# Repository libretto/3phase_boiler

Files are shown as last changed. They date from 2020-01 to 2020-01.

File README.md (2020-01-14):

# 3phase boiler controller project
Arduino based control unit circuit and firmware

# WARNING!!!  This code was created for my own test and study purposes and finally was implemented in DIY project for three phase 360V heater.
# DISCLAIMER! Any reproducing of the unit and usage it with high voltage devices is at your own risk!

History of project: 
I had cheap 12kW (360V) water heater in home climate system which had a problem with contactor frequently and I replaced it few times per season. 
To avoid this issue I decide include Solid State Relays with digital thermostat to heater circuit (serial connection to contactor based termostat for better safety).
This solution replaced mechanical switching with spark which destroy contactor to semiconductor switching and algorithm in thermostat reduced switches of heater to possible minimum.
I decide create my own thermostat circuit using Arduino nano as module to which i can connect LCD, Encoder, Sensors and SSR (or magnetic relay for other appliances). 

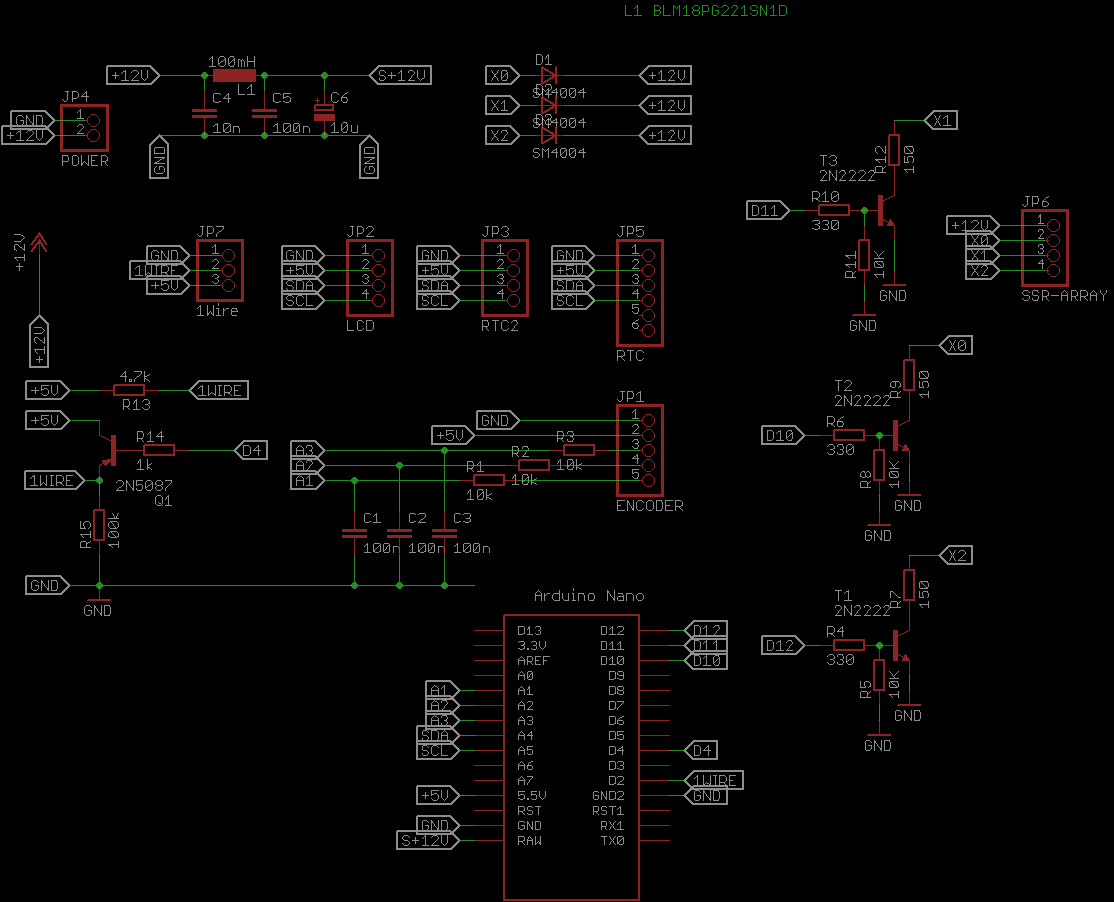
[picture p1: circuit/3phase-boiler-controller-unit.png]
Arduino based three phase control module circuit


Required units:

Arduino Nano, 
Encoder unit KY-040 (with 3 10k resistors on board), 
LCD 1602 with I2C adaptor, 
SSR Fotek SSR-40DA 3 pcs, 
DS18B20 thermal sensor with holder module 

List of all semiconductor components is included in Eagle project.

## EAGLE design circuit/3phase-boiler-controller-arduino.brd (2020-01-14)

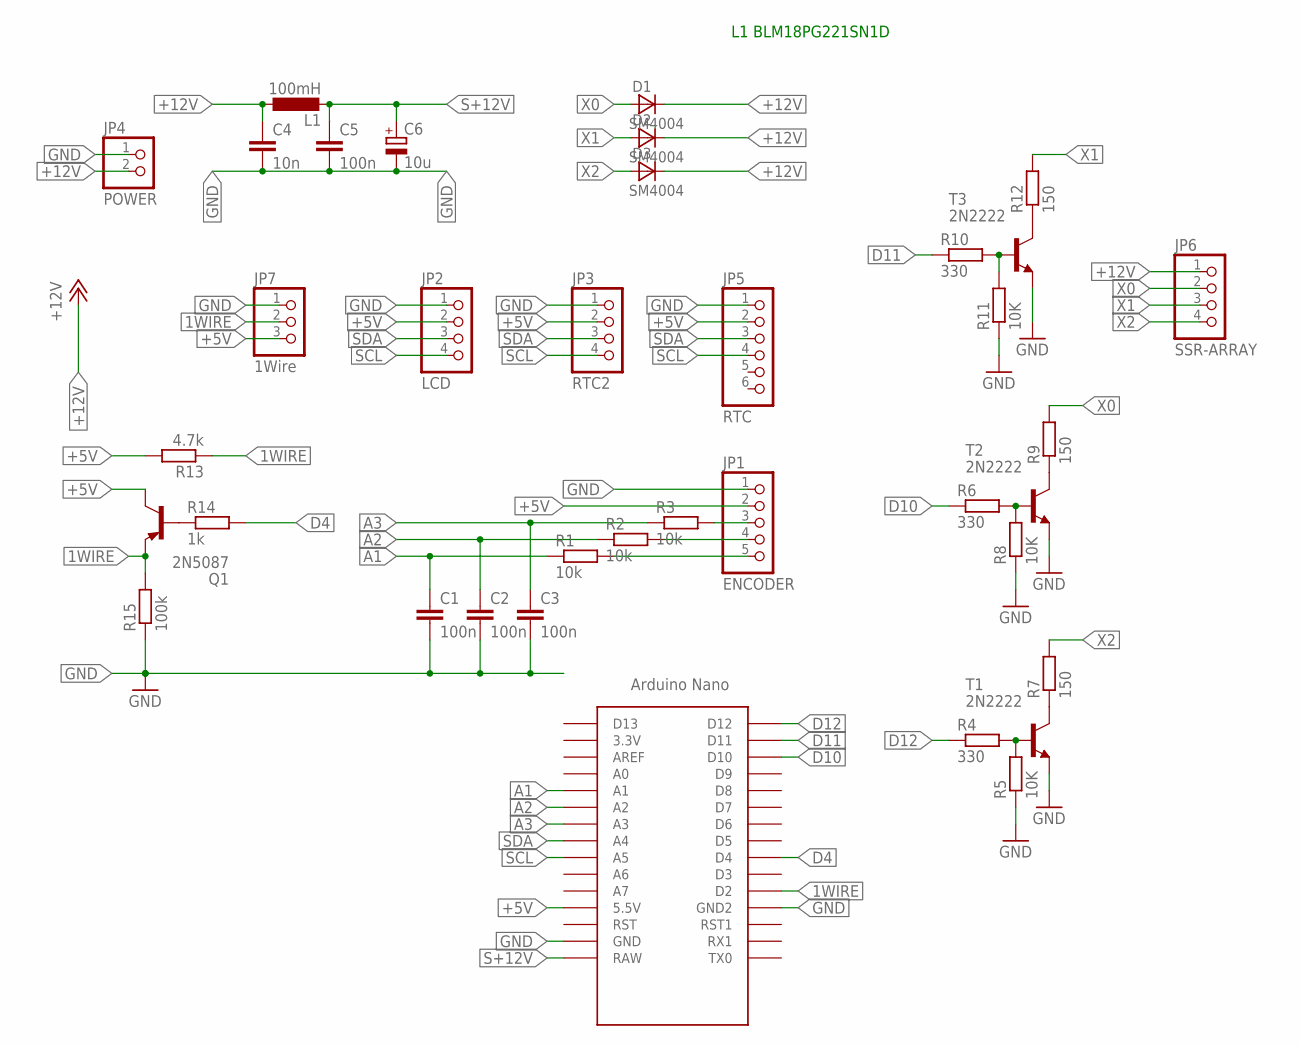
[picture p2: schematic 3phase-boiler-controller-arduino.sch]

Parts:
C1, C2, C3, C5: 100n; C0603
C4: 10n; C0603
C6: 10u; 153CLV-0807
D1, D2, D3: SM4004; MELF-MLL41
JP1: ENCODER; 1X05
JP2: LCD; 1X04
JP3: RTC2; 1X04
JP4: POWER; 1X02
JP5: RTC; 1X06/90
JP6: SSR-ARRAY; 1X04
JP7: 1Wire; 1X03
L1: 100mH; 0207/12
Q1: 2N5087; TO92
R1, R2, R3: 10k; R0805
R4, R6, R10: 330; R0805
R5, R8, R11: 10K; R0805
R7, R9, R12: 150; R0805
R13: 4.7k; R0805
R14: 1k; R0805
R15: 100k; R0805
T1, T2, T3: 2N2222; TO92-EBC-OVAL
U$1: NANO

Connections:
1WIRE: JP7.2, Q1.3 (E), R13.1, R15.2, U$1.D2
+5V: JP1.2, JP2.2, JP3.2, JP5.2, JP7.3, Q1.1 (C), R13.2, U$1.5V (5.5V)
+12V: C4.1, D1.C, D2.C, D3.C, JP4.2, JP6.1, L1.1
A1: C1.1, R1.1, U$1.A1
A2: C2.1, R2.1, U$1.A2
A3: C3.1, R3.1, U$1.A3
CLK: JP1.5, R1.2
D4: R14.2, U$1.D4
D10: R6.1, U$1.D10
D11: R10.1, U$1.D11
D12: R4.1, U$1.D12
DT: JP1.4, R2.2
GND: C1.2, C2.2, C3.2, C4.2, C5.2, C6.-, JP1.1, JP2.1, JP3.1, JP4.1, JP5.1, JP7.1, R5.1, R8.1, R11.1, R15.1, T1.E, T2.E, T3.E, U$1.GND, U$1.GND1 (GND2)
unnamed: R6.2, R8.2, T2.B
unnamed: R9.1, T2.C
unnamed: R10.2, R11.2, T3.B
unnamed: R12.1, T3.C
unnamed: R4.2, R5.2, T1.B
unnamed: R7.1, T1.C
unnamed: Q1.2 (B), R14.1
S+12V: C5.1, C6.+, L1.2, U$1.RAW
SCL: JP2.4, JP3.4, JP5.4, U$1.A5
SDA: JP2.3, JP3.3, JP5.3, U$1.A4
SW: JP1.3, R3.2
X0: D1.A, JP6.2, R9.2
X1: D2.A, JP6.3, R12.2
X2: D3.A, JP6.4, R7.2

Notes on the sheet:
L1 BLM18PG221SN1D

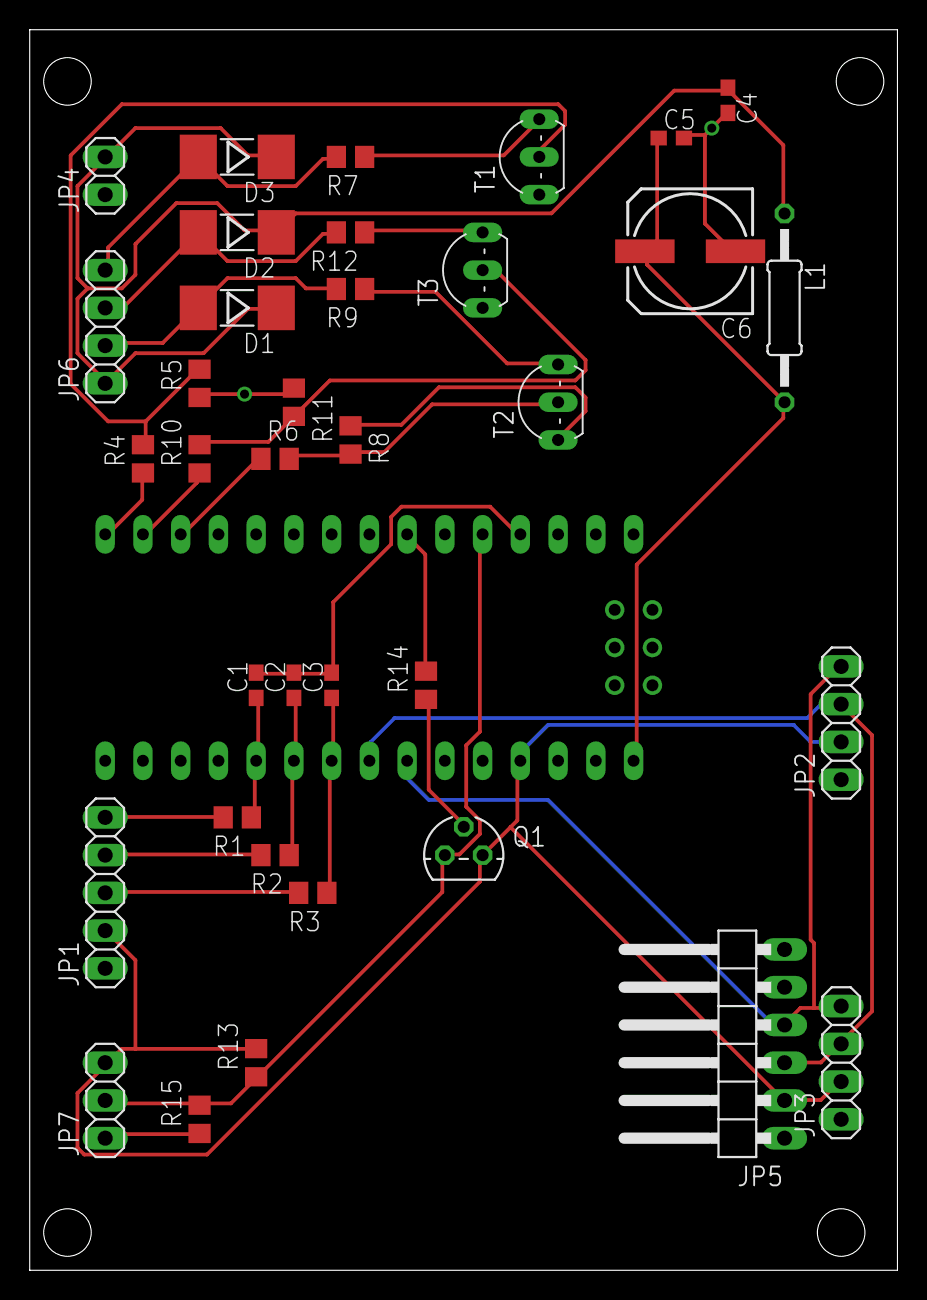
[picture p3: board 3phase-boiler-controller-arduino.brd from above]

Board: 2 copper layers, 58.4 x 83.5 mm, 37 parts (0 on the bottom side), 27 nets.

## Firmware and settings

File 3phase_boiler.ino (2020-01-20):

// WARNING!!!
// This code was created for study and tests purposes for my personal use only.
// Any reproducing of the unit and this code usage with high voltage devices is at your own risk!

#include <EEPROM.h>
#include <OneWire.h>
#include <DallasTemperature.h>
#include <LiquidCrystal_I2C.h>
#include <avr/wdt.h>

/*
   DS1307RTC required for day-night feature of heating algorithm
   and it will not require ATMega328P board because of firmware memory consumption)


  #include <TimeLib.h>
  #include <Time.h>
  #include <DS1307RTC.h> */

#define ONE_WIRE_BUS 2

#define TARGET_MODE 0
#define STATUS_MODE 1
#define LOG_MODE 2
#define CONFIGURE_SENSORMAP_MODE 3
#define MAX_MODE 3

#define SENSOR_RESOLUTION 10

int relay_map[3] = {11, 10, 12}; // relay pins
boolean relay_state[3];
int t_watchdog = 0;
unsigned long last_keypress = 0;
unsigned long mode_timeout = 0;
unsigned long logic_delay = 0;



byte sensors_map[6][3] = {
  {0, 1, 2},
  {0, 2, 1},
  {1, 0, 2},
  {1, 2, 0},
  {2, 0, 1},
  {2, 1, 0}
};

float temperatures[3] = { 0, 0, 0 };
float hysteresis = 2;

float target_t;
float last_temp_in = 0;
boolean must_grow = true;
boolean pause = false;


byte mode = TARGET_MODE;
boolean draw_flag = false;
int lcd_key     = 0;
int adc_key_in  = 0;


OneWire oneWire(ONE_WIRE_BUS);
DallasTemperature sensors(&oneWire);
//LiquidCrystal_I2C lcd(0x3F, 16, 2);
LiquidCrystal_I2C lcd(0x27, 16, 2);

struct Settings {
  float delta;
  byte sensor_map_id;
};

volatile byte sensor_map_id;
volatile float delta;

unsigned long previousMillis = 0;
unsigned long logicMillis = 0;
unsigned long pause_switch_logic_millis = 0;
Settings settings;

DeviceAddress sensorDeviceAddress;
boolean saved = true;

void setup()
{

  Serial.begin(9600);
  /*setSyncProvider(RTC.get);
    if (timeStatus() != timeSet)
    Serial.println("Unable to sync with the RTC");
    else
    Serial.println("RTC has set the system time");
  */

  lcd.init();                      // initialize the lcd
  lcd.backlight();
  lcd.setCursor(0, 1);
  lcd.print("                ");
  lcd.print("Init:           ");



  EEPROM.get(0, settings);

  if (isnan(settings.sensor_map_id) ) { // First Time check
    Serial.println("set default settings");
    settings.sensor_map_id = 0;
    settings.delta = 2;
  }

  sensor_map_id = settings.sensor_map_id;
  delta = settings.delta;
  saved = true;
  for (byte i = 0; i < 3; i++) {
    pinMode(relay_map[i], OUTPUT);
  }
  all_relays_off();


  sensors.begin();
  sensors.setResolution(SENSOR_RESOLUTION);
  //sensors.setWaitForConversion(false);
  //////Serial.println(sensors.getDeviceCount());
  //sensors.requestTemperatures();

  //sensors.getAddress(sensorDeviceAddress, 0);
  //printAddress(sensorDeviceAddress);
  //sensors.setResolution(sensorDeviceAddress, SENSOR_RESOLUTION);

  //sensors.getAddress(sensorDeviceAddress, 1);
  //printAddress(sensorDeviceAddress);
  //sensors.setResolution(sensorDeviceAddress, SENSOR_RESOLUTION);
  //sensors.getAddress(sensorDeviceAddress, 2);
  //printAddress(sensorDeviceAddress);
  //sensors.setResolution(sensorDeviceAddress, SENSOR_RESOLUTION);
  sensors.setWaitForConversion(false);
  sensors.requestTemperatures();

  pinMode(A1, INPUT);
  pinMode(A2, INPUT);
  pinMode(A3, INPUT);
  digitalWrite(A1, HIGH);
  digitalWrite(A2, HIGH);
  digitalWrite(A3, HIGH);
  PCICR =  0b00000010;
  PCMSK1 = 0b00001110;
  wdt_disable();
  delay(3000);
  wdt_enable(WDTO_2S);

}

volatile byte seqA = 0;
volatile byte seqB = 0;
volatile byte seqC = 0;
volatile byte cnt1 = 0;
volatile byte cnt2 = 0;


int volume = 0;
byte up = 0;
byte isClick = 0;

volatile byte reading = 0;
volatile byte encoder_data;
volatile boolean encoder_event = false;
#define ENCODER_LEFT 0x01
#define ENCODER_RIGHT 0x02
#define ENCODER_DOWN 0x04

int last_button;
int timeout = 94 << (SENSOR_RESOLUTION - 9);

// Encoder events by interrupt

ISR(PCINT1_vect) {

  boolean C_val = digitalRead(A3);
  boolean A_val = digitalRead(A1);
  boolean B_val = digitalRead(A2);
  byte enc = 0;

  seqA <<= 1;
  seqA |= A_val;

  seqB <<= 1;
  seqB |= B_val;

  seqA &= 0b00001111;
  seqB &= 0b00001111;

  if (seqA == 0b00001001 && seqB == 0b00000011)
  {
    enc |= ENCODER_RIGHT;
    encoder_event = true;
  }

  if (seqA == 0b00000011 && seqB == 0b00001001)
  {
    enc |= ENCODER_LEFT;
    encoder_event = true;
  }

  if (!C_val) {
    enc |= ENCODER_DOWN;
    encoder_event = true;
  }
  encoder_data = enc;

}


void loop() {
  if (encoder_event) {
    input(encoder_data);
  }

  print_mode();
  pass();
  wdt_reset();
}

inline void  input(byte enc) {
  //Serial.println(enc);

  saved = true;
  encoder_event = false;
  last_keypress = millis();
  mode_timeout = last_keypress;
  draw_flag = true;
  if ((enc & ENCODER_DOWN ) == ENCODER_DOWN) {
    mode++;
    if (mode > MAX_MODE) {
      mode = 0;
    }
    return;
  }
  if ( enc == 0 ) {
    return;
  }
  if (mode == STATUS_MODE || mode == LOG_MODE) {
    mode = TARGET_MODE;
  }

  if (mode == TARGET_MODE) {
    if ( (enc & ENCODER_LEFT) == ENCODER_LEFT ) {
      delta += 0.5;
    } else {
      delta -= 0.5;
    }
  }

  if (mode == CONFIGURE_SENSORMAP_MODE) {
    if ( (enc & ENCODER_LEFT) == ENCODER_LEFT ) {
      if (sensor_map_id < 5) {
        sensor_map_id ++;
      }
      else {
        sensor_map_id = 0 ;
      }
    } else {
      if (sensor_map_id > 0) {
        sensor_map_id --;
      } else {
        sensor_map_id = 5;
      }
    }
  }
}



void pass() {
  if (sensor_map_id != settings.sensor_map_id) {
    settings.sensor_map_id = sensor_map_id;
    saved = false;
  }
  if (delta != settings.delta) {
    settings.delta = delta;
    saved = false;
    logicMillis = 0;
  }

  if (sensor_map_id > 5) {
    sensor_map_id = 0;
    delta = 0;
  }
  last_button = 0;
  check_idle();

  if (millis() - previousMillis > timeout * 8)
  {
    for (int i = 0; i < 3; i++) {
      float temp_read = sensors.getTempCByIndex(i);
      if (temp_read > -99 && temp_read < 99) {
        temperatures[i] = temp_read;
      }
    }
    sensors.setWaitForConversion(false);
    sensors.requestTemperatures();
    //sensors.setWaitForConversion(true);
    previousMillis = millis();
  }

  if (millis() - logicMillis > 2000) {
    logic();
    logicMillis = millis();
  }
}

void print_mode() {
  if (draw_flag) {
    if (mode == STATUS_MODE ) {
      print_status();
    }
    if (mode == TARGET_MODE) {
      print_target_t();
    }
    if (mode == CONFIGURE_SENSORMAP_MODE) {
      print_sensormap();
    }
    if (mode == LOG_MODE) {
      print_log();
    }
    draw_flag = false;
  }
  if (abs(millis() - mode_timeout) > 2000) {
    mode_timeout = millis();
    mode ++;
    draw_flag = true;
    if (mode > 2) {
      mode = 0;
    }
  }
}

void print_status() {
  print_temperature();
  print_relay_status();
}



void print_sensormap() {
  lcd.setCursor(0, 0);
  lcd.print("In Out Outdr");
  lcd.setCursor(0, 1);           // move cursor to second line "1" and 9 spaces over
  for (int i = 0; i < 3; i++) {
    int ssid = sensors_map[sensor_map_id][i];
    float temp = temperatures[ssid];
    if (temp > 50) {
      temp = 99;
    }
    lcd.print(temp, 1);
    lcd.print(";");
  }
  lcd.print("   ");
}

void print_log() {
  // want see uptime...
  lcd.setCursor(0, 0);

  lcd.print("Up:");
  lcd.print((millis() / 3600000));
  lcd.print("h         ");
  lcd.setCursor(0, 1);
  lcd.print(last_temp_in);
  lcd.print(":");
  lcd.print(t_watchdog);
  lcd.print("    ");
}

void print_temperature() {
  lcd.setCursor(0, 0);           // move cursor to second line "1" and 9 spaces over
  for (int i = 0; i < 3; i++) {
    int ssid = sensors_map[sensor_map_id][i];
    float temp = temperatures[ssid];
    if (temp > 99) {
      temp = 99;
    }
    if (temp < -99) {
      temp = -99;
    }
    lcd.print(temp, 1);
    lcd.print(";");
  }
  lcd.print("   ");
}

void check_idle() {

  if (abs(millis() - last_keypress) > 5000 ) {
    if (!saved) {
      lcd.setCursor(0, 1);
      lcd.print("sav X ");
      EEPROM.put(0, settings);
      saved = true;
    }
  }
}



void logic() {

  float t_out = temperatures[1]; //not implemented yet
  float t_in = temperatures[0];
  float t_outdoor = temperatures[2]; //not implemented yet
  //Serial.println("logic");
  if (t_out < -50) {
    t_out = 20; // ignore sensor
  }

  if (t_in < -50) {
    t_in = 90; // shut down heaters if error with this sensor
  }
  if (t_outdoor < -50) {
    t_outdoor = 20; // ignore sensor
  }

  target_t = 43 - 0.8 * t_outdoor + delta;

  if (last_temp_in == t_in) {
    t_watchdog ++;
  } else {
    t_watchdog = 0;
  }

  if (t_in - hysteresis * 2 > target_t || t_watchdog > 1000) {
    all_relays_off();
    must_grow = false;
    checkin(t_in);
  }

  if (t_in < target_t - hysteresis) {
    must_grow = true;
    power_up(t_in);
  }

  if ( millis() - pause_switch_logic_millis < logic_delay ) { //
    return;
  }

  if (t_in > target_t + hysteresis) {
    must_grow = false;
    power_down(t_in);
  }

  if ( t_in < target_t + hysteresis && t_in > target_t - hysteresis ) {

    if (must_grow && t_in < last_temp_in) {
      power_up(t_in);
    }

    if (!must_grow && t_in > last_temp_in) {
      power_down(t_in);
    }
  }
}


void power_up(float t_in) {
  for (byte i = 0; i < 3; i++) {
    if (!relay_state[i]) {
      relay_on(i);
      break;
    }
  }
  checkin(t_in);
}

void power_down(float t_in) {
  for (byte i = 3; i > 0; i--) {
    if (relay_state[i - 1]) {
      relay_off(i - 1);
      break;
    }
  }
  checkin(t_in);
}

void checkin(float t_in) {
  last_temp_in = t_in;

  // empirical heating timeouts TODO
  if (must_grow) {
    pause_switch_logic_millis = millis();
    logic_delay = 180000;
  } else {
    pause_switch_logic_millis = millis();
    logic_delay = 180000;
  }
}
void relay_off(byte relay_id) {
  relay_state[relay_id] = false;
  digitalWrite(relay_map[relay_id], LOW);
}

void relay_on(byte relay_id) {
  if (relay_state[relay_id]) return;
  relay_state[relay_id] = true;
  digitalWrite(relay_map[relay_id], HIGH);
}


void all_relays_on() {
  for (byte i = 0; i < 3; i++) {
    relay_on(i);
  }
};

void all_relays_off() {
  for (byte i = 0; i < 3; i++) {
    relay_off(i);
  }
};



void print_relay_status() {

  lcd.setCursor(0, 1);
  lcd.print("Head:");
  for (byte i = 0; i < 3; i++) {
    if (relay_state[i]) {
      lcd.print("[*]");
    } else {
      lcd.print("[ ]");
    }
  }
  lcd.print("    ");
}

void print_target_t() {
  lcd.setCursor(0, 0);
  lcd.print("Target temp:    ");
  lcd.setCursor(0, 1);
  lcd.print(target_t, 1);
  lcd.print(" C               ");
}

void printAddress(DeviceAddress deviceAddress)
{
  for (uint8_t i = 0; i < 8; i++)
  {
    if (deviceAddress[i] < 16)
      Serial.print(deviceAddress[i], HEX);
  }
}

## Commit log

2020-01-14 beta release
    [3phase-boiler-controller-arduino.brd, 3phase-boiler-controller-arduino.sch]
2020-01-15 change function names and update logic delays for smooth power change
2020-01-16 debug speed 1-wire timing
2020-01-20 tune logic, add watchdog, improve encoder handler to minimize interrupt time
2020-01-20 fixup screen modes, add debug/log screen
    [3phase_boiler.ino]
